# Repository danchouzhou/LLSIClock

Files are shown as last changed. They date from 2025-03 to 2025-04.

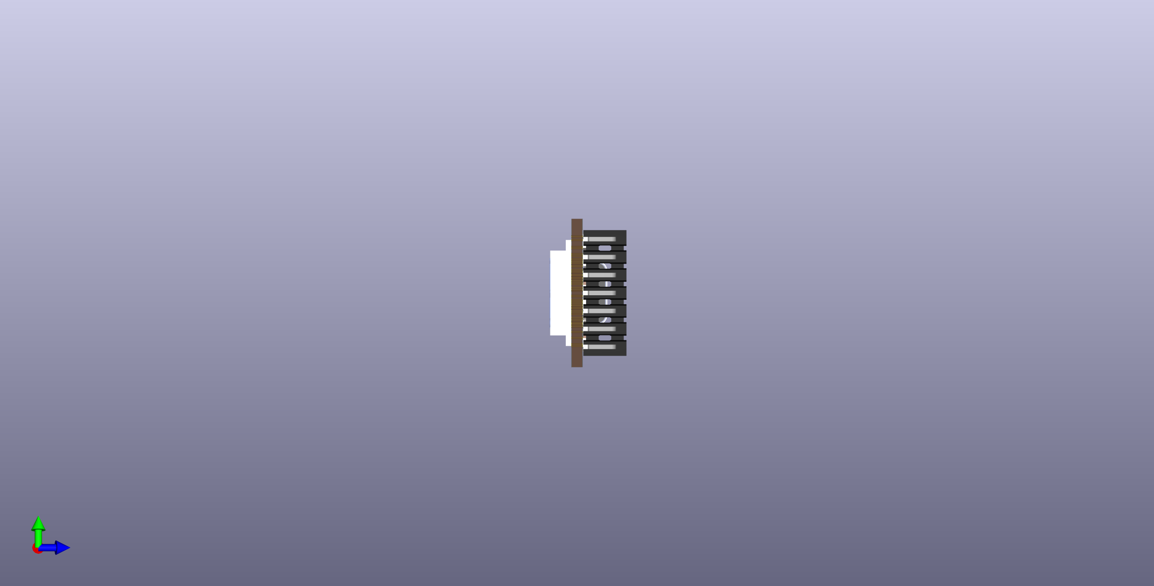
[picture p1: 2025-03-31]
kicad/LLSIClock_side.png

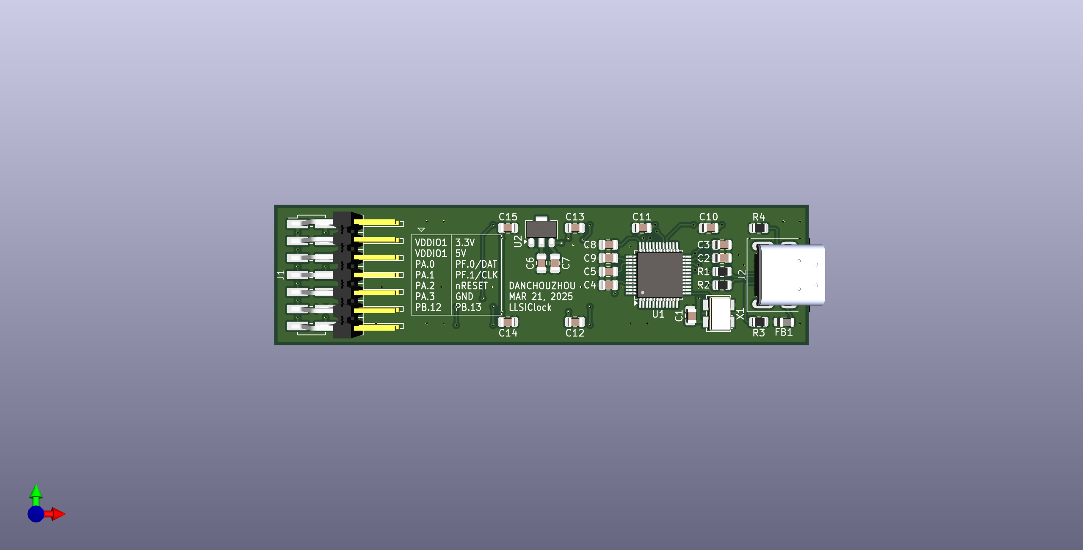
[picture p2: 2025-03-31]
kicad/LLSIClock.png

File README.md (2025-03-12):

# Nuvoton Visual Studio Code Template
## Usage
### To clone this project
This project work with submodule from Nuvoton corporation. You need to initialize submodules by passing ``--recurse-submodules`` to the ``git clone`` command.
```
git clone https://github.com/danchouzhou/Nuvoton-VScode-template.git --recurse-submodules
```

### Build tools
#### Windows users
Since we use VScode ``setting.json`` provide the build environment, only the execution binary need to be download (without installing). Download the following files, extract to the path ``C:\Users\"Your user name"\BuildTools\Windows`` which specific in ``.vscode/setting.json``.
- [gcc-arm-none-eabi-10.3-2021.07-win32.zip](https://developer.arm.com/downloads/-/gnu-rm)
- [xpack-windows-build-tools-4.3.0-1-win32-x64.zip
](https://github.com/xpack-dev-tools/windows-build-tools-xpack/releases/tag/v4.3.0-1)
- [OpenOCD-Nuvoton](https://github.com/OpenNuvoton/OpenOCD-Nuvoton/releases)
#### Linux users
- [gcc-arm-none-eabi-10.3-2021.07-x86_64-linux.tar.bz2](https://developer.arm.com/downloads/-/gnu-rm)
- [OpenOCD-Nuvoton](https://github.com/OpenNuvoton/OpenOCD-Nuvoton/releases)
```
mkdir -p ~/BuildTools/Linux/
tar jxvf gcc-arm-none-eabi-10.3-2021.07-x86_64-linux.tar.bz2 -C ~/BuildTools/Linux/
unzip OpenOCD_Linux.zip -d ~/BuildTools/Linux/
chmod +x ~/BuildTools/Linux/OpenOCD/bin/openocd
```
- GNU Make should be installed.
```
sudo apt install make
```
### Build the template
If you want to build the target for Nuvoton M480 series for example. Open a terminal inside the VScode.
```
cd firmware/LLSI_RGBW
```
Simply ``make``. ``LLSI_RGBW.bin`` should be inside the ``Objects`` folder.
```
make
```
### Flash the firmware
```
make flash
```
For Linux users, probably need to add the access permission for usb device.
```
sudo chmod -R 777 /dev/bus/usb/
```
### Rebuild
```
make clean
make
```

### Create your own project from this template
1. Add BSP submodule from [OpenNuvoton](https://github.com/OpenNuvoton). For example:
```
git submodule add https://github.com/OpenNuvoton/M480BSP.git NuMicro-M4/M480BSP
```
2. Edit ``CORTEX_M``, ``BASE``, ``DEVICE`` in the ``makefile.conf``.

## Reference
- [A Simple Makefile Tutorial](https://www.cs.colby.edu/maxwell/courses/tutorials/maketutor/)
- [Makefile Tutorial By Example](https://makefiletutorial.com/)
- [Git - Submodules](https://git-scm.com/book/en/v2/Git-Tools-Submodules)
- [Set global $PATH environment variable in VS Code - Stack Overflow](https://stackoverflow.com/questions/43983718/set-global-path-environment-variable-in-vs-code)
- [Flashing firmware with OpenOCD without using telnet](https://acassis.wordpress.com/2016/08/22/flashing-firmware-with-openocd-without-using-telnet/)

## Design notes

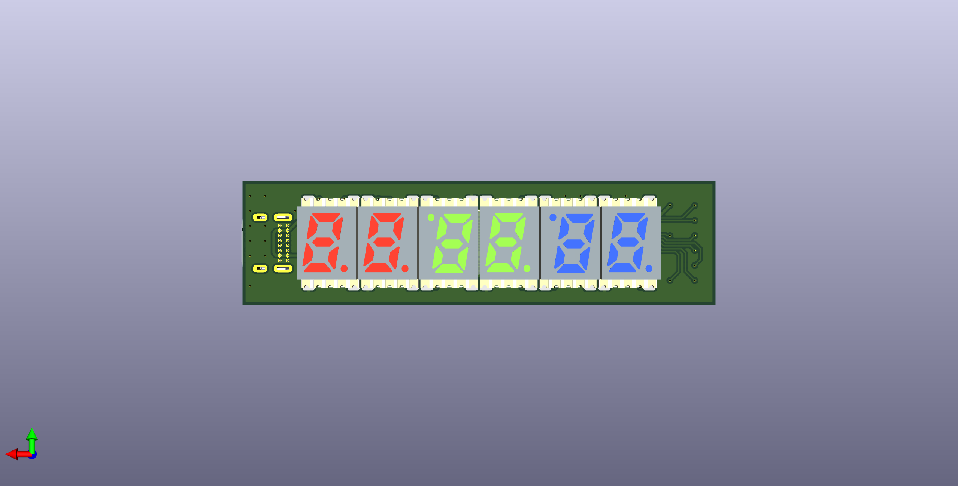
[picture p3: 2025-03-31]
kicad/LLSIClock_back.png

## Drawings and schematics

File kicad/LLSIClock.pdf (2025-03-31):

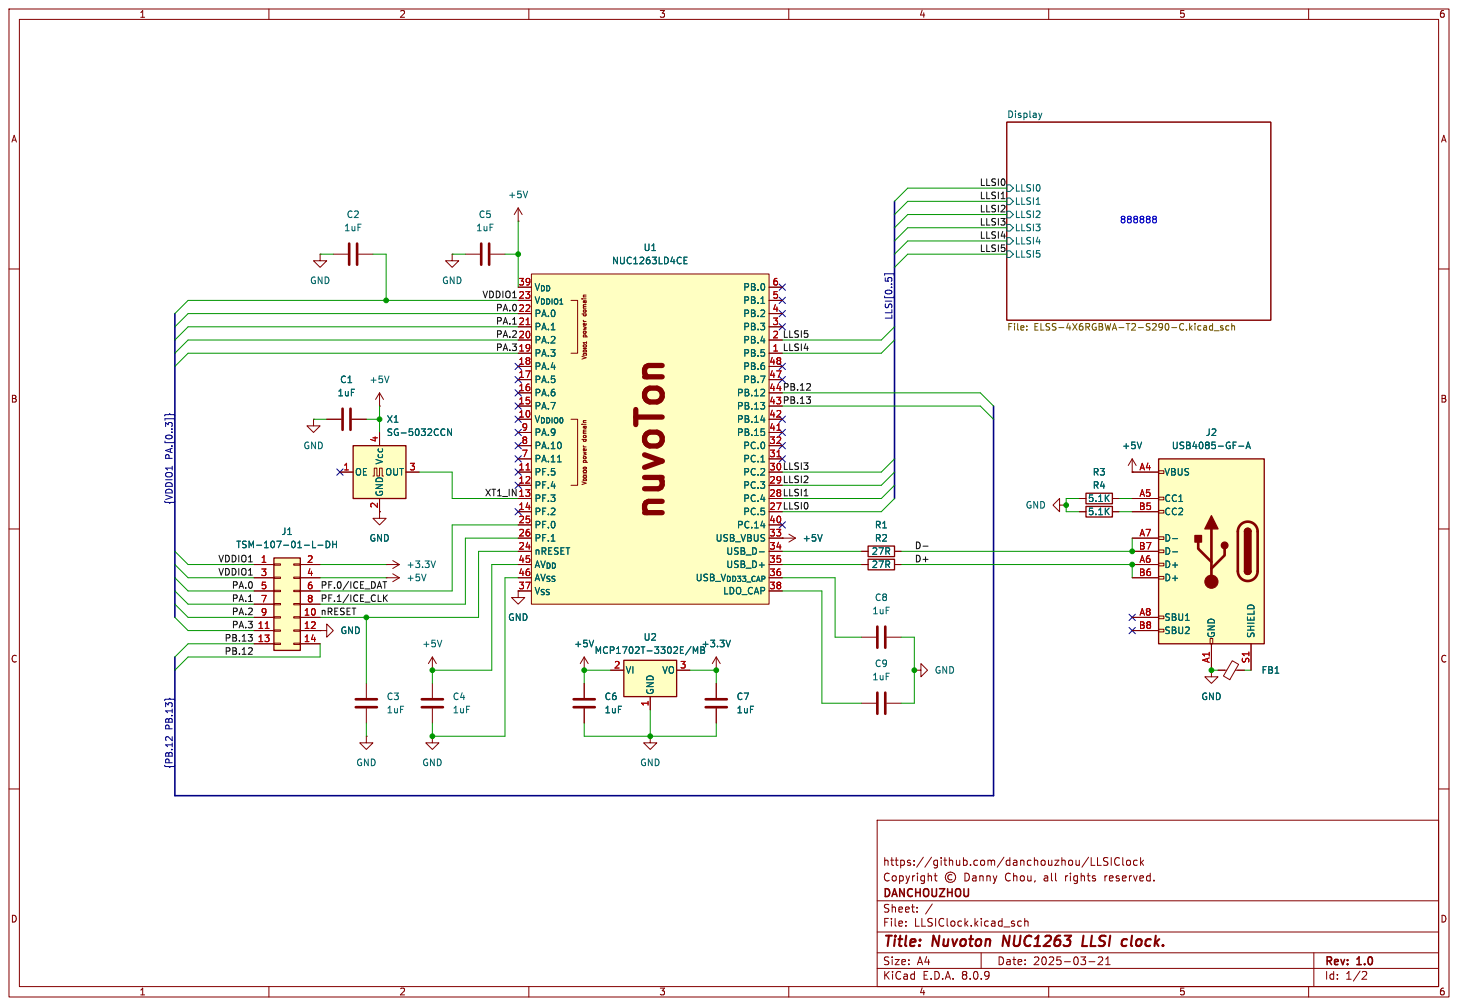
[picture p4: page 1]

2 OUT 3 Vcc 4 GND GND
+5V GND GND

Id: 1/2 Title: Nuvoton NUC1263 LLSI clock. File: LLSIClock.kicad_sch Sheet: / DANCHOUZHOU

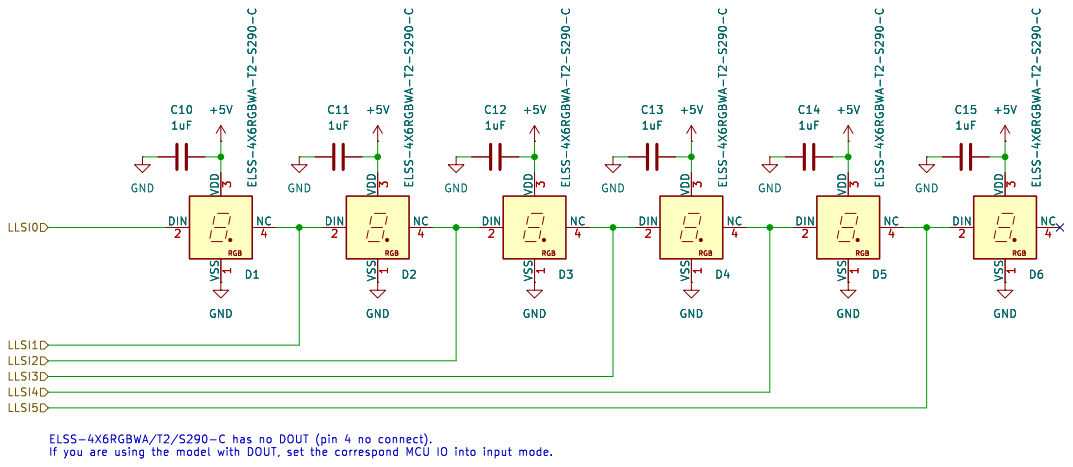
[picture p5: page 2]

Id: 2/2 Title: Nuvoton NUC1263 LLSI clock. File: ELSS-4X6RGBWA-T2-S290-C.kicad_sch Sheet: /Display/ DANCHOUZHOU

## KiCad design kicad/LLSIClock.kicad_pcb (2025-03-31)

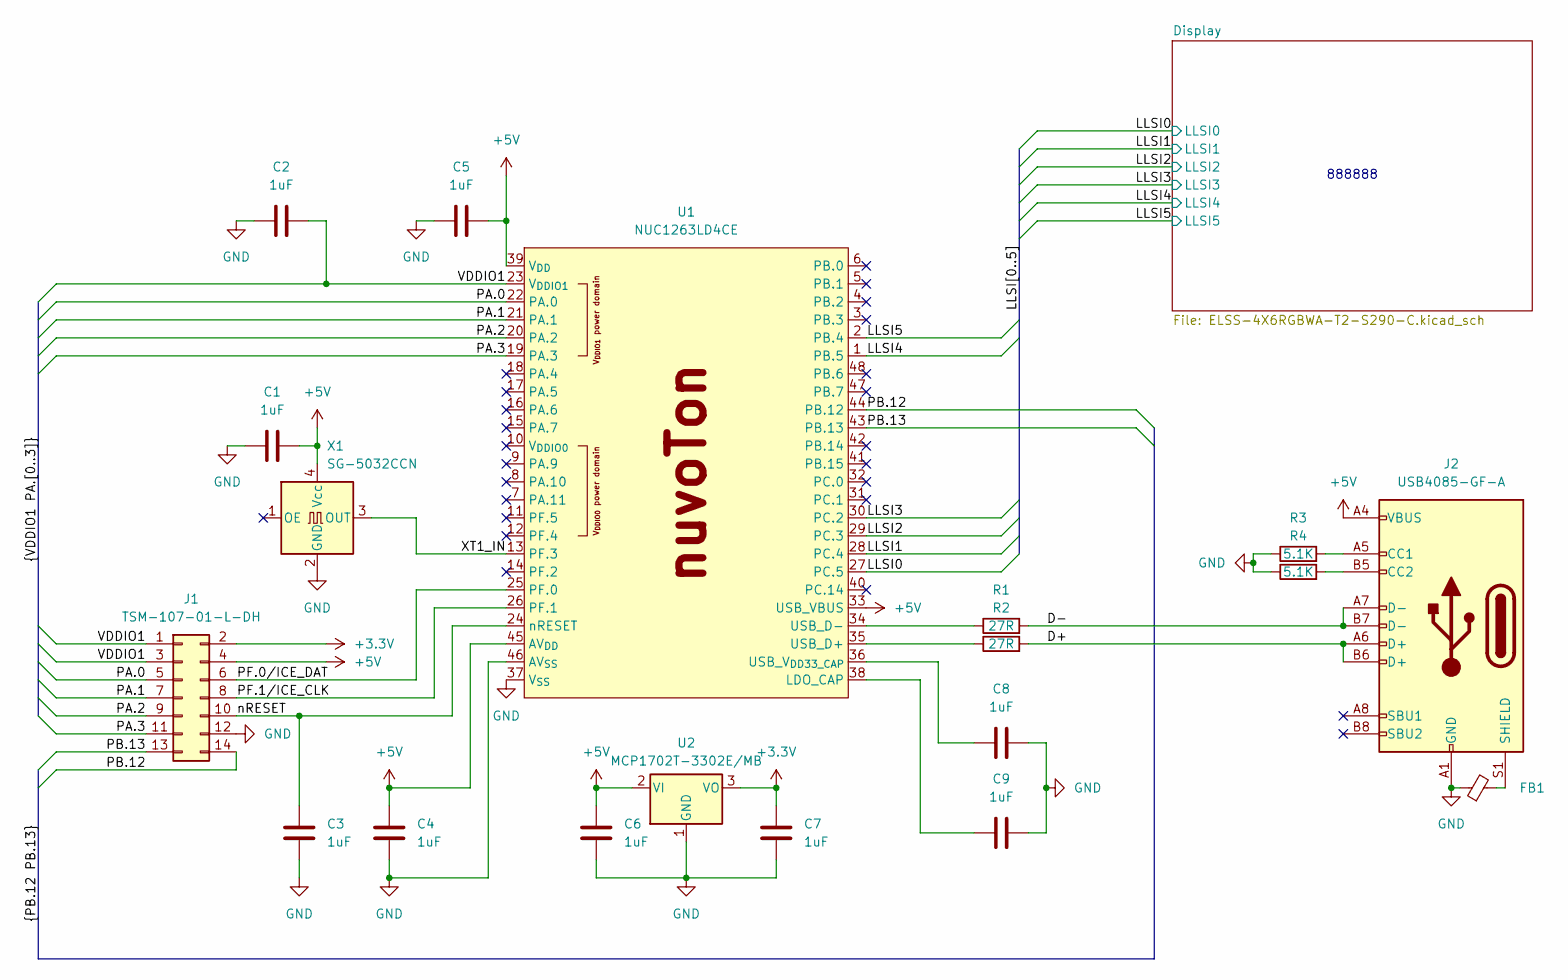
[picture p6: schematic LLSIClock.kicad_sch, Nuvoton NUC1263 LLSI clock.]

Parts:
C1, C2, C3, C4, C5, C6, C7, C8, C9: 1uF; C_0805_2012Metric
FB1: FerriteBead_Small; L_0805_2012Metric
J1: TSM-107-01-L-DH
J2: USB4085-GF-A; 2137160001_USB4085
R1, R2: 27R; R_0805_2012Metric
R3, R4: 5.1K; R_0805_2012Metric
U1: NUC1263LD4CE; LQFP-48_7x7mm_P0.5mm
U2: MCP1702T-3302E/MB; SOT-89-3
X1: SG-5032CCN; Oscillator_SMD_SeikoEpson_SG8002LB-4Pin_5.0x3.2mm

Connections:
+3.3V: C7.1, J1.2, U2.3 (VO)
+5V: C1.2, C4.1, C5.2, C6.1, J1.4, J2.A4 (VBUS), J2.A9 (VBUS), J2.B4 (VBUS), J2.B9 (VBUS), U1.33 (USB_VBUS), U1.39 (V_{DD}), U1.45 (AV_{DD}), U2.2 (VI), X1.4 (Vcc); also elsewhere on the board
/D+: J2.A6 (D+), J2.B6 (D+), R2.2
/D-: J2.A7 (D-), J2.B7 (D-), R1.2
/LLSI0: U1.27 (PC.5); also elsewhere on the board
/LLSI1: U1.28 (PC.4); also elsewhere on the board
/LLSI2: U1.29 (PC.3); also elsewhere on the board
/LLSI3: U1.30 (PC.2); also elsewhere on the board
/LLSI4: U1.1 (PB.5); also elsewhere on the board
/LLSI5: U1.2 (PB.4); also elsewhere on the board
/PA.0: J1.5, U1.22 (PA.0)
/PA.1: J1.7, U1.21 (PA.1)
/PA.2: J1.9, U1.20 (PA.2)
/PA.3: J1.11, U1.19 (PA.3)
/PB.12: J1.14, U1.44 (PB.12)
/PB.13: J1.13, U1.43 (PB.13)
/PF.0/ICE_DAT: J1.6, U1.25 (PF.0)
/PF.1/ICE_CLK: J1.8, U1.26 (PF.1)
/VDDIO1: C2.2, J1.1, J1.3, U1.23 (V_{DDIO1})
/XT1_IN: U1.13 (PF.3), X1.3 (OUT)
/nRESET: C3.1, J1.10, U1.24 (nRESET)
GND: C1.1, C2.1, C3.2, C4.2, C5.1, C6.2, C7.2, C8.2, C9.2, FB1.1, J1.12, J2.A1 (GND), J2.A12 (GND), J2.B1 (GND), J2.B12 (GND), R3.1, R4.1, U1.37 (V_{SS}), U1.46 (AV_{SS}), U2.1 (GND), X1.2 (GND); also elsewhere on the board
unnamed: J2.A5 (CC1), R3.2
unnamed: J2.B5 (CC2), R4.2
unnamed: FB1.2, J2.S1 (SHIELD)
unnamed: C9.1, U1.38 (LDO_CAP)
unnamed: R2.1, U1.35 (USB_D+)
unnamed: R1.1, U1.34 (USB_D-)
unnamed: C8.1, U1.36 (USB_V_{DD33_CAP})

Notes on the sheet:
888888

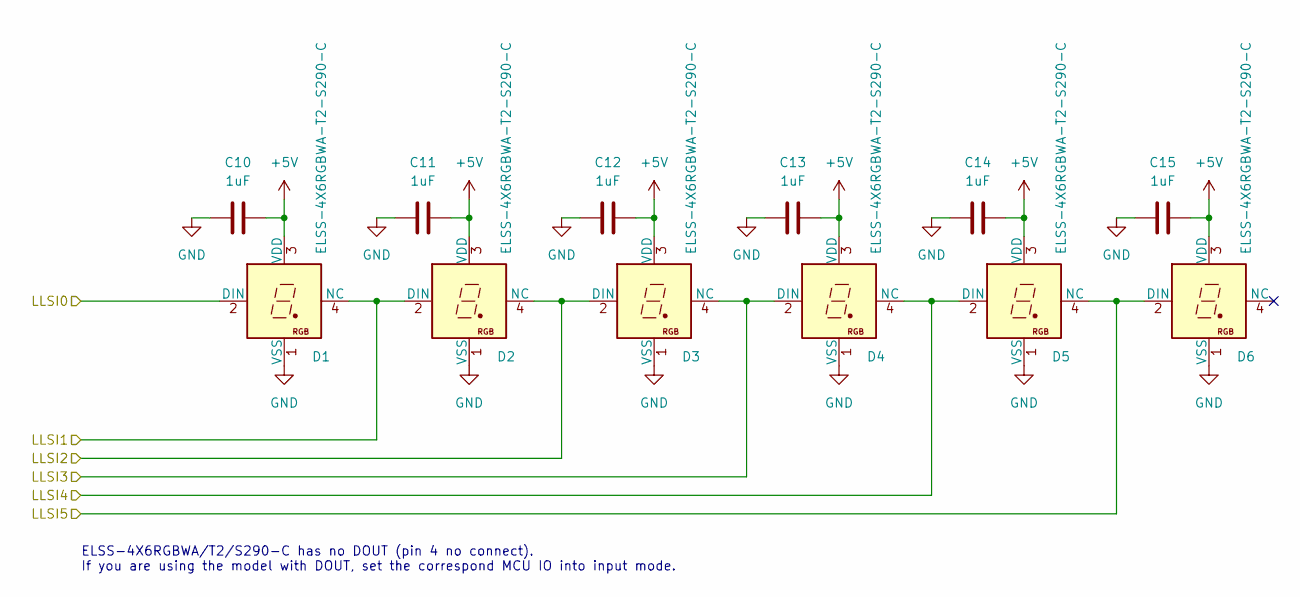
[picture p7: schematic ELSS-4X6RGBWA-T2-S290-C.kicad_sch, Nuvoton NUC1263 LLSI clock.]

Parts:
C10, C11, C12, C13, C14, C15: 1uF; C_0805_2012Metric
D1, D2, D3, D4, D5, D6: ELSS-4X6RGBWA-T2-S290-C

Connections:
+5V: C10.2, C11.2, C12.2, C13.2, C14.2, C15.2, D1.3 (VDD), D2.3 (VDD), D3.3 (VDD), D4.3 (VDD), D5.3 (VDD), D6.3 (VDD); also elsewhere on the board
/LLSI0: D1.2 (DIN); also elsewhere on the board
/LLSI1: D1.4 (NC), D2.2 (DIN); also elsewhere on the board
/LLSI2: D2.4 (NC), D3.2 (DIN); also elsewhere on the board
/LLSI3: D3.4 (NC), D4.2 (DIN); also elsewhere on the board
/LLSI4: D4.4 (NC), D5.2 (DIN); also elsewhere on the board
/LLSI5: D5.4 (NC), D6.2 (DIN); also elsewhere on the board
GND: C10.1, C11.1, C12.1, C13.1, C14.1, C15.1, D1.1 (VSS), D2.1 (VSS), D3.1 (VSS), D4.1 (VSS), D5.1 (VSS), D6.1 (VSS); also elsewhere on the board

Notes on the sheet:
ELSS-4X6RGBWA/T2/S290-C has no DOUT (pin 4 no connect). If you are using the model with DOUT, set the correspond MCU IO into input mode.

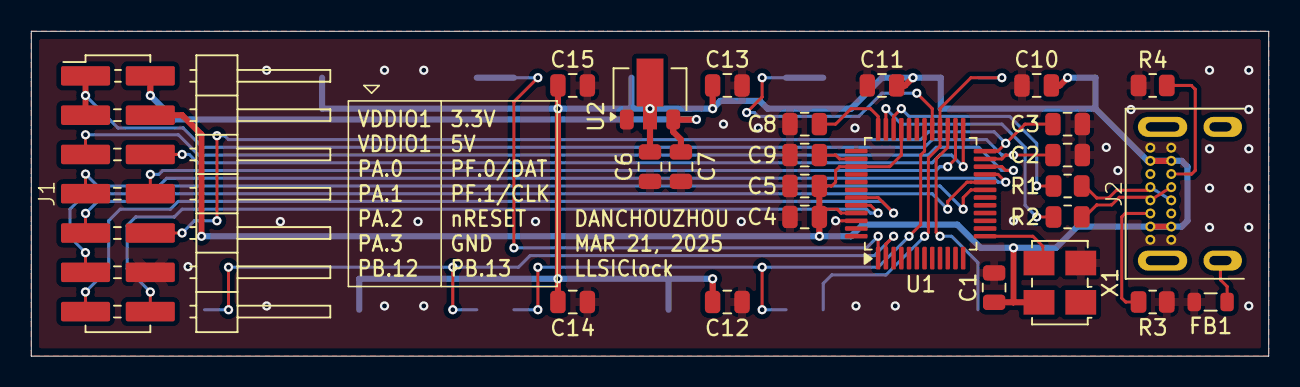
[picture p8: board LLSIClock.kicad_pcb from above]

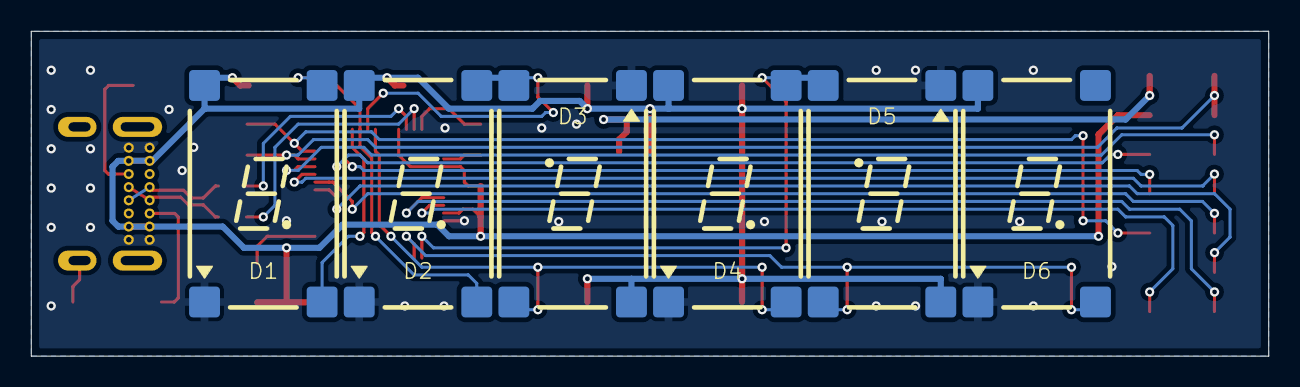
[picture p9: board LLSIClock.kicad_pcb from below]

Board: 2 copper layers, 80.0 x 21.0 mm, 31 parts (6 on the bottom side), 29 nets.

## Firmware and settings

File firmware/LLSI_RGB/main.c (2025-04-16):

#include <stdio.h>
#include "NuMicro.h"

#define HCLK_CLK    72000000
#define TEST_COUNT  6

//                         2nd   1st
// 32-bit color format is 0xRRBBGGRR for the ELSS-4X6RGBWA/T2/S290-C
volatile uint8_t g_au8frameBuffer[24] = {
    0x80, 0x00, 0x00, // Red
    0x80, 0x20, 0x00, // Orange
    0x40, 0x40, 0x00, // Yellow
    0x00, 0x80, 0x00, // Green
    0x00, 0x00, 0xFF, // Blue
    0x00, 0x40, 0x80, // Indigo
    0x80, 0x00, 0xFF, // Violet
    0x80, 0x80, 0x80  // White
};
volatile uint32_t g_u32DataCount = 0;
volatile uint32_t g_u32FrameEnd = 0;

void LLSI0_IRQHandler()
{
    if (LLSI_GetIntFlag(LLSI0, LLSI_TXTH_INT_MASK))
    {
        while(LLSI_GET_TX_FIFO_FULL_FLAG(LLSI0) == 0) // Fill up the TX FIFO
        {
            if (g_u32DataCount == (TEST_COUNT - 1))
                LLSI_SET_LAST_DATA(LLSI0); // Before writing last word data to LLSI_DATA, user must write LDT = 1
            
            if (g_u32DataCount < TEST_COUNT)
                LLSI_WRITE_DATA(LLSI0, *((uint32_t *)g_au8frameBuffer + g_u32DataCount++));
            else
                break;
        }

        if(g_u32DataCount >= TEST_COUNT)
        {
            LLSI_DisableInt(LLSI0, LLSI_TXTH_INT_MASK);
        }
    }

    if (LLSI_GetIntFlag(LLSI0, LLSI_FEND_INT_MASK)) // FENDIF will be set to 1 when LLSI transfer last pixel data.
    {
        g_u32FrameEnd = 1;
        LLSI_ClearIntFlag(LLSI0, LLSI_FEND_INT_MASK);
    }
}

void SYS_Init(void)
{
    /*---------------------------------------------------------------------------------------------------------*/
    /* Init System Clock                                                                                       */
    /*---------------------------------------------------------------------------------------------------------*/
    /* Enable HIRC clock */
    CLK_EnableXtalRC(CLK_PWRCTL_HIRCEN_Msk);

    /* Wait for HIRC clock ready */
    CLK_WaitClockReady(CLK_STATUS_HIRCSTB_Msk);

    /* Set core clock to HCLK_CLK Hz */
    CLK_SetCoreClock(HCLK_CLK);

    /* Enable UART0 module clock */
    CLK_EnableModuleClock(UART0_MODULE);

    /* Select UART0 module clock source as HIRC/2 and UART0 module clock divider as 1 */
    CLK_SetModuleClock(UART0_MODULE, CLK_CLKSEL1_UART0SEL_HIRC_DIV2, CLK_CLKDIV0_UART0(1));

    /* Enable LLSI0 module clock */
    CLK_EnableModuleClock(LLSI0_MODULE);

    /*---------------------------------------------------------------------------------------------------------*/
    /* Init I/O Multi-function                                                                                 */
    /*---------------------------------------------------------------------------------------------------------*/
    /* Set PB multi-function pins for UART0 RXD and TXD */
    SYS->GPB_MFPH = (SYS->GPB_MFPH & (~(UART0_RXD_PB12_Msk | UART0_TXD_PB13_Msk))) | UART0_RXD_PB12 | UART0_TXD_PB13;

    /* Set PC multi-function pins for LLSI0 */
    SET_LLSI0_OUT_PC5();
}

void UART0_Init()
{
    /*---------------------------------------------------------------------------------------------------------*/
    /* Init UART                                                                                               */
    /*---------------------------------------------------------------------------------------------------------*/
    /* Reset UART0 module */
    SYS_ResetModule(UART0_RST);

    /* Configure UART0 and set UART0 Baudrate */
    UART_Open(UART0, 115200);
}

void LLSI_Init(void)
{
    /*---------------------------------------------------------------------------------------------------------*/
    /* Init LLSI                                                                                               */
    /*---------------------------------------------------------------------------------------------------------*/
    /* Configure as software mode, RGB output format, 8 pixels in a frame and idle output low */
    /* Set clock divider. LLSI clock rate = 72MHz */
    /* Set data transfer period. T_Period = 1250ns */
    /* Set duty period. T_T0H = 400ns; T_T1H = 850ns */
    /* Set reset command period. T_ResetPeriod = 50000ns */
    LLSI_Open(LLSI0, LLSI_MODE_SW, LLSI_FORMAT_RGB, HCLK_CLK, 1250, 400, 850, 50000, 8, LLSI_IDLE_LOW);

    /* Set TX FIFO threshold */
    LLSI_SetFIFO(LLSI0, 2);

    /* Enable reset command function */
    LLSI_ENABLE_RESET_COMMAND(LLSI0);

    NVIC_EnableIRQ(LLSI0_IRQn);
}

void main(void)
{
    uint8_t u8Tmp;
    
    /* Unlock protected registers */
    SYS_UnlockReg();

    /* Init System, IP clock and multi-function I/O. */
    SYS_Init();

    /* Lock protected registers */
    SYS_LockReg();

    /* Init UART0 for printf */
    UART_Open(UART0, 115200);

    printf("\n\nCPU @ %d Hz\n", SystemCoreClock);

    /* Init LLSI */
    LLSI_Init();

    /* Enable Transmit FIFO Threshold Interrupt and Frame End Interrupt */
    LLSI_EnableInt(LLSI0, LLSI_TXTH_INT_MASK | LLSI_FEND_INT_MASK);

    /* Write the first word to trigger TXTH_INT */
    LLSI_WRITE_DATA(LLSI0, *((uint32_t *)g_au8frameBuffer + g_u32DataCount++));

    while(1)
    {
        if (g_u32FrameEnd == 1)  // Wait for FEND_INT
        {
            for (int i=0; i<3; i++)
            {
                u8Tmp = g_au8frameBuffer[23];

                for (int j=23; j>0; j--)
                    g_au8frameBuffer[j] = g_au8frameBuffer[j-1];
                
                g_au8frameBuffer[0] = u8Tmp;
            }

            g_u32FrameEnd = 0;
            g_u32DataCount = 0;

            LLSI_EnableInt(LLSI0, LLSI_TXTH_INT_MASK);
            
            CLK_SysTickLongDelay(500000);
        }
    }
}

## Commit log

2025-03-28 1. Add LLSI_RGBW_PDMA
    2. Correct pixel count comment
    3. Update c_cpp_properties.json
    [main.c]
2025-03-29 Add LLSI_RGB SampleCode
2025-03-31 Add KiCad files
    [ELSS-4X6RGBWA-T2-S290-C.kicad_sch, LLSIClock.kicad_pcb, LLSIClock.kicad_sch]

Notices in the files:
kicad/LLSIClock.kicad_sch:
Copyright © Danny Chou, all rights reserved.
